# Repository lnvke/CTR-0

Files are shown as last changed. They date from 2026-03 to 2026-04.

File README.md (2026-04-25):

# CTR-0
Cheaper Than aRduino is a custom devboard meant to be a cost-effective alternative my choice of the Arduino Nano series of devboard hobbyist microcontrollers. It is based of the same RP2040 microcontroller and will provide similar performance compared to its more costly counterpart, the Arduino Nano V3, which is the board I usually use for projects that require a microcontroller.



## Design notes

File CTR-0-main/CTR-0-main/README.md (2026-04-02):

# CTR-0
Cheaper Than aRduino is a custom devboard meant to be a cost-effective alternative my choice of the Arduino Nano series of devboard hobbyist microcontrollers. It is based of the same RP2040 microcontroller and will provide similar performance compared to its more costly counterpart, the Arduino Nano V3, which is the board I have been using.

## Roadmap
- finalize parts
  -finish footprints for any new parts
- pcb footprint, general size
  - placement/routing first pass
- cost optimization
- routing second pass
- final route optimization
- send gerbers to JLCPCB and order
- assemble
- done

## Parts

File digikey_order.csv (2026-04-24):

Index | Quantity | Part Number | Manufacturer Part Number | Description | Customer Reference | Available | Backorder | Unit Price | Extended Price USD
1 | 2 | 311-1017-1-ND | CC0402JRNPO9BN150 | CAP CER 15PF 50V C0G/NPO 0402 |  | 2 | 0 | 0.10000 | 0.20
2 | 11 | 311-1338-1-ND | CC0402KRX7R7BB104 | CAP CER 0.1UF 16V X7R 0402 |  | 11 | 0 | 0.02700 | 0.30
3 | 2 | S1011EC-20-ND | PRPC020SAAN-RC | CONN HEADER VERT 20POS 2.54MM |  | 2 | 0 | 0.60000 | 1.20
4 | 2 | 311-5.10KLRCT-ND | RC0402FR-075K1L | RES 5.1K OHM 1% 1/16W 0402 |  | 2 | 0 | 0.10000 | 0.20
5 | 2 | YAG3086CT-ND | RC0402FR-0727RL | RES 27 OHM 1% 1/16W 0402 |  | 2 | 0 | 0.10000 | 0.20
6 | 2 | 311-10.0KLRCT-ND | RC0402FR-0710KL | RES 10K OHM 1% 1/16W 0402 |  | 2 | 0 | 0.10000 | 0.20
7 | 1 | 2648-SC0914(13)CT-ND | SC0914(13) | IC MCU 32B EXT MEM 56QFN RP2040 |  | 1 | 0 | 0.76000 | 0.76
8 | 1 | NCP1117ST33T3GOSCT-ND | NCP1117ST33T3G | IC REG LINEAR 3.3V 1A SOT-223 |  | 1 | 0 | 0.60000 | 0.60
9 | 1 | MX25L12872FM2I-10G-ND | MX25L12872FM2I-10G | IC FLASH 128MBIT SPI/QUAD 8SOP |  | 1 | 0 | 2.82000 | 2.82
10 | 2 | 4809-SKRKAEE020CT-ND | SKRKAEE020 | SWITCH TACTILE SPST-NO 0.05A 12V |  | 2 | 0 | 0.41000 | 0.82
11 | 1 | 2073-USB4105-GF-ACT-ND | USB4105-GF-A | CONN RCP USB2.0 TYP C 16P SMD RA |  | 1 | 0 | 0.80000 | 0.80
12 | 2 | 311-1448-1-ND | CC0603MRX5R5BB106 | CAP CER 10UF 6.3V X5R 0603 |  | 2 | 0 | 0.24000 | 0.48
13 | 1 | 311-1730-1-ND | CC0402MRX5R5BB475 | CAP CER 4.7UF 6.3V X5R 0402 |  | 1 | 0 | 0.17000 | 0.17
14 | 2 | 311-1438-1-ND | CC0402KRX5R5BB105 | CAP CER 1UF 6.3V X5R 0402 |  | 2 | 0 | 0.10000 | 0.20
15 | 1 | S1011EC-03-ND | PRPC003SAAN-RC | CONN HEADER VERT 3POS 2.54MM |  | 1 | 0 | 0.32000 | 0.32
16 | 3 | 311-1.00KLRCT-ND | RC0402FR-071KL | RES 1K OHM 1% 1/16W 0402 |  | 3 | 0 | 0.10000 | 0.30
17 | 1 | 296-50511-1-ND | TVS1400DRVR | UNIDIR PRECISION SURGE DIODE |  | 1 | 0 | 1.03000 | 1.03
18 | 1 | 535-9137-1-ND | ABM8-22.1184MHZ-B2-T | CRYSTAL 22.1184MHZ 18PF SMD |  | 1 | 0 | 0.43000 | 0.43

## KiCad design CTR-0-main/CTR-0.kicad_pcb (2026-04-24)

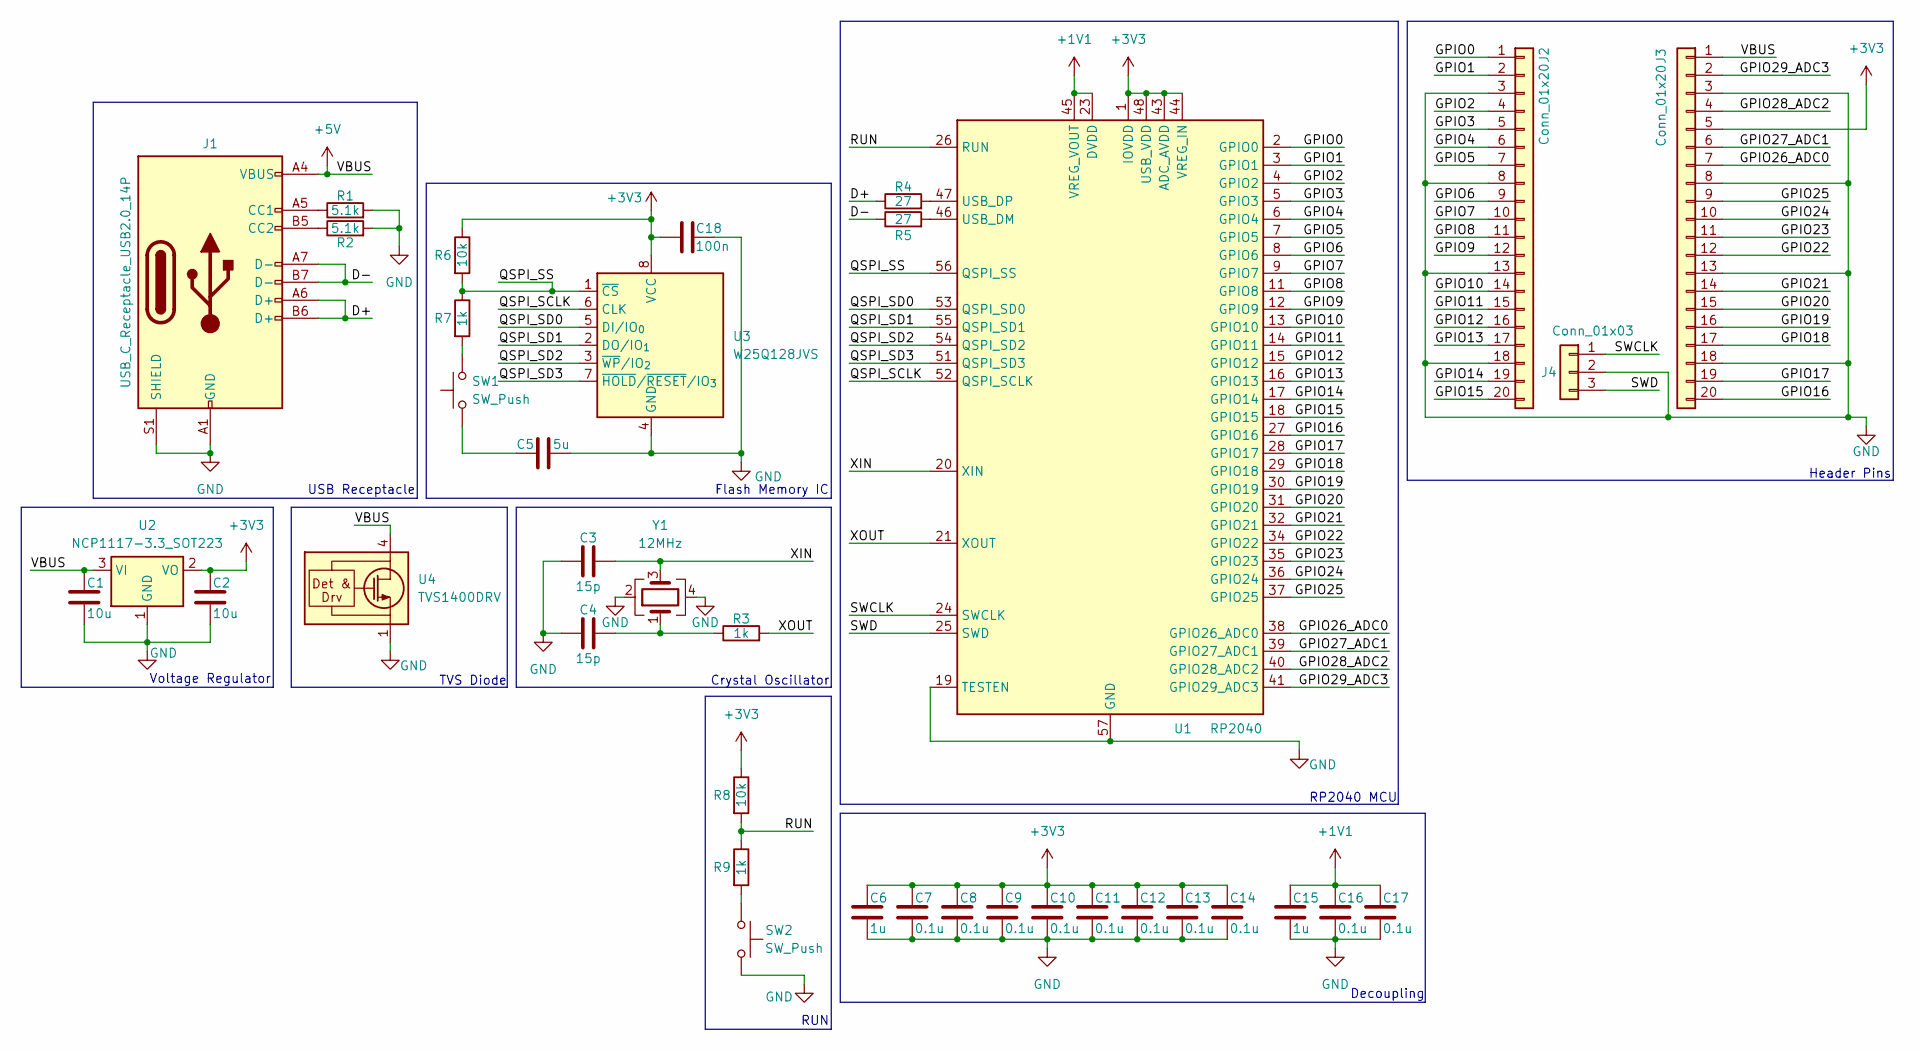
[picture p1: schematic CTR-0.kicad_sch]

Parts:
C1, C2: 10u; C_0603_1608Metric
C3, C4: 15p; C_0402_1005Metric
C5: 5u; C_0402_1005Metric
C6, C15: 1u; C_0402_1005Metric
C7, C8, C9, C10, C11, C12, C13, C14, C16, C17: 0.1u; C_0402_1005Metric
C18: 100n; C_0402_1005Metric
J1: USB_C_Receptacle_USB2.0_14P; USB_C_Receptacle_GCT_USB4105-xx-A_16P_TopMnt_Horizontal
J2, J3: Conn_01x20; PinHeader_1x20_P2.54mm_Vertical
J4: Conn_01x03; PinHeader_1x03_P2.54mm_Vertical
R1, R2: 5.1k; R_0402_1005Metric
R3, R7, R9: 1k; R_0402_1005Metric
R4, R5: 27; R_0402_1005Metric
R6, R8: 10k; R_0402_1005Metric
SW1, SW2: SW_Push; SW_Push_SPST_NO_Alps_SKRK
U1: RP2040; QFN-56-1EP_7x7mm_P0.4mm_EP3.2x3.2mm
U2: NCP1117-3.3_SOT223; SOT-223-3_TabPin2
U3: W25Q128JVS; SOIC-8_5.3x5.3mm_P1.27mm
U4: TVS1400DRV; WSON-6-1EP_2x2mm_P0.65mm_EP1x1.6mm
Y1: 12MHz; Crystal_SMD_3225-4Pin_3.2x2.5mm

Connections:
+1V1: C15.1, C16.1, C17.1, U1.23 (DVDD), U1.45 (VREG_VOUT), U1.50 (DVDD)
+3V3: C2.1, C6.1, C7.1, C8.1, C9.1, C10.1, C11.1, C12.1, C13.1, C14.1, C18.2, J3.5, R6.1, R8.1, U1.1 (IOVDD), U1.10 (IOVDD), U1.22 (IOVDD), U1.33 (IOVDD), U1.42 (IOVDD), U1.43 (ADC_AVDD), U1.44 (VREG_IN), U1.48 (USB_VDD), U1.49 (IOVDD), U2.2 (VO), U3.8 (VCC)
+5V: C1.1, J1.A4 (VBUS), J1.A9 (VBUS), J1.B4 (VBUS), J1.B9 (VBUS), J3.1, U2.3 (VI), U4.4 (IN), U4.5 (IN), U4.6 (IN)
/D+: J1.A6 (D+), J1.B6 (D+), R4.1
/D-: J1.A7 (D-), J1.B7 (D-), R5.1
/GPIO0: J2.1, U1.2 (GPIO0)
/GPIO1: J2.2, U1.3 (GPIO1)
/GPIO2: J2.4, U1.4 (GPIO2)
/GPIO3: J2.5, U1.5 (GPIO3)
/GPIO4: J2.6, U1.6 (GPIO4)
/GPIO5: J2.7, U1.7 (GPIO5)
/GPIO6: J2.9, U1.8 (GPIO6)
/GPIO7: J2.10, U1.9 (GPIO7)
/GPIO8: J2.11, U1.11 (GPIO8)
/GPIO9: J2.12, U1.12 (GPIO9)
/GPIO10: J2.14, U1.13 (GPIO10)
/GPIO11: J2.15, U1.14 (GPIO11)
/GPIO12: J2.16, U1.15 (GPIO12)
/GPIO13: J2.17, U1.16 (GPIO13)
/GPIO14: J2.19, U1.17 (GPIO14)
/GPIO15: J2.20, U1.18 (GPIO15)
/GPIO16: J3.20, U1.27 (GPIO16)
/GPIO17: J3.19, U1.28 (GPIO17)
/GPIO18: J3.17, U1.29 (GPIO18)
/GPIO19: J3.16, U1.30 (GPIO19)
/GPIO20: J3.15, U1.31 (GPIO20)
/GPIO21: J3.14, U1.32 (GPIO21)
/GPIO22: J3.12, U1.34 (GPIO22)
/GPIO23: J3.11, U1.35 (GPIO23)
/GPIO24: J3.10, U1.36 (GPIO24)
/GPIO25: J3.9, U1.37 (GPIO25)
/GPIO26_ADC0: J3.7, U1.38 (GPIO26_ADC0)
/GPIO27_ADC1: J3.6, U1.39 (GPIO27_ADC1)
/GPIO28_ADC2: J3.4, U1.40 (GPIO28_ADC2)
/GPIO29_ADC3: J3.2, U1.41 (GPIO29_ADC3)
/QSPI_SCLK: U1.52 (QSPI_SCLK), U3.6 (CLK)
/QSPI_SD0: U1.53 (QSPI_SD0), U3.5 (DI/IO_{0})
/QSPI_SD1: U1.55 (QSPI_SD1), U3.2 (DO/IO_{1})
/QSPI_SD2: U1.54 (QSPI_SD2), U3.3 (~WP/IO_{2})
/QSPI_SD3: U1.51 (QSPI_SD3), U3.7 (~HOLD/~RESET/IO_{3})
/QSPI_SS: R6.2, R7.1, U1.56 (QSPI_SS), U3.1 (~CS)
/RUN: R8.2, R9.1, U1.26 (RUN)
/SWCLK: J4.1, U1.24 (SWCLK)
/SWD: J4.3, U1.25 (SWD)
/XIN: C3.2, U1.20 (XIN), Y1.3
/XOUT: R3.2, U1.21 (XOUT)
GND: C1.2, C2.2, C3.1, C4.1, C5.1, C6.2, C7.2, C8.2, C9.2, C10.2, C11.2, C12.2, C13.2, C14.2, C15.2, C16.2, C17.2, C18.1, J1.A1 (GND), J1.A12 (GND), J1.B1 (GND), J1.B12 (GND), J1.S1 (SHIELD), J2.3, J2.8, J2.13, J2.18, J3.3, J3.8, J3.13, J3.18, J4.2, R1.2, R2.2, SW2.1, U1.19 (TESTEN), U1.57 (GND), U2.1 (GND), U3.4 (GND), U4.1 (GND), U4.2 (GND), U4.3 (GND), U4.7 (GND), Y1.2, Y1.4
unnamed: C4.2, R3.1, Y1.1
unnamed: C5.2, SW1.1
unnamed: J1.A5 (CC1), R1.1
unnamed: J1.B5 (CC2), R2.1
unnamed: R7.2, SW1.2
unnamed: R9.2, SW2.2
unnamed: R5.2, U1.46 (USB_DM)
unnamed: R4.2, U1.47 (USB_DP)

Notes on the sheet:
RP2040 MCU
Flash Memory IC
Crystal Oscillator
Decoupling
RUN
TVS Diode
Voltage Regulator
USB Receptacle
Header Pins

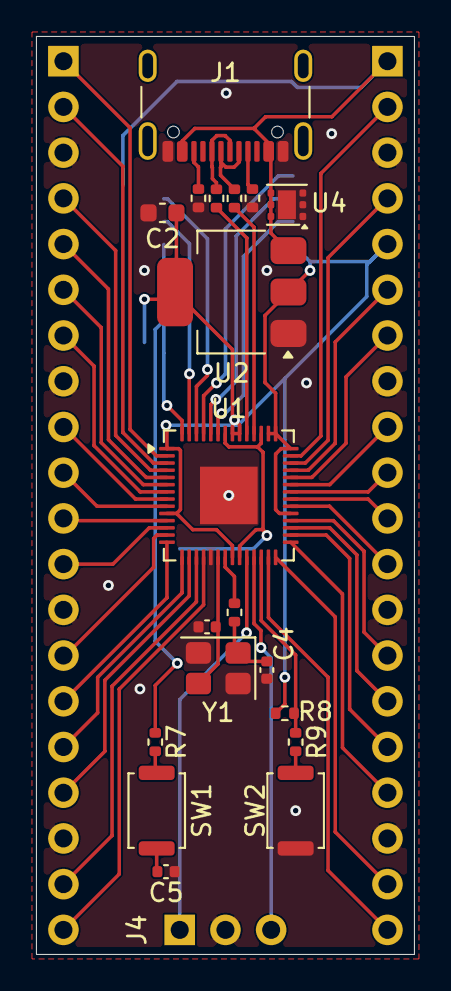
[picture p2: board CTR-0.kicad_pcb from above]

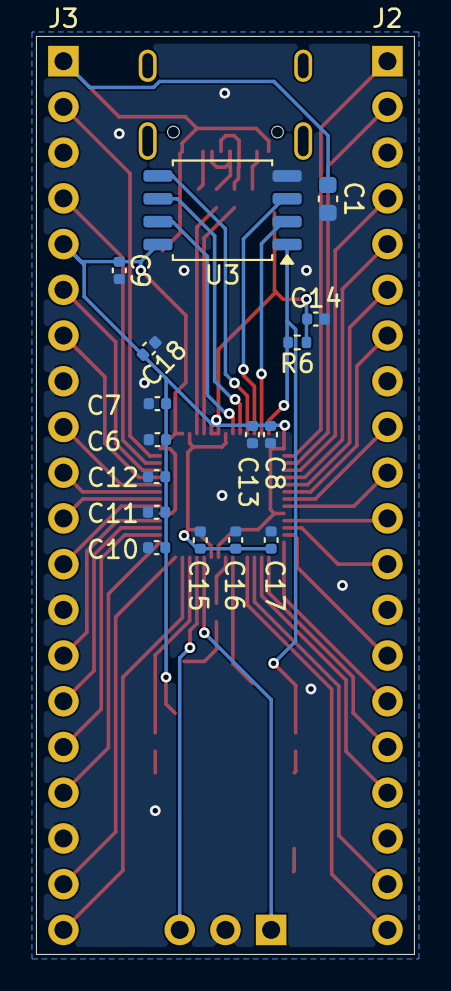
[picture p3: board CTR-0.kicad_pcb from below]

Board: 2 copper layers, 21.0 x 51.0 mm, 38 parts (18 on the bottom side), 55 nets.

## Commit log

2026-03-24 Add files via upload
    updated schematic, fixed schematic errors
    updated footprints, settled on larger form factor parts for easier assembly
    updated pcb, ground plane + rough placement first pass
2026-03-26 fixed push
    [CTR-0.kicad_pcb, CTR-0.kicad_sch]
2026-03-28 final first route
    [CTR-0.kicad_pcb]
2026-04-02 reroute #2
    does not fulfill drc, fix errors and clearance
    [CTR-0.kicad_pcb, CTR-0.kicad_sch]
2026-04-10 fixes+final route
    +decoupling capacitors
    -clearance errors
    -library footprint errors
    [CTR-0.kicad_pcb]
2026-04-23 fix
    gnd plane drc fix
2026-04-23 fix
    footprints now obey drc, component graphics now obey drc
    [CTR-0.kicad_pcb]
2026-04-24 fixed footprints for bom
    out of stock parts replaced
    [CTR-0.kicad_pcb, CTR-0.kicad_sch]
2026-04-24 edit
    updated footprints
    [CTR-0.kicad_sch, digikey_order.csv]
